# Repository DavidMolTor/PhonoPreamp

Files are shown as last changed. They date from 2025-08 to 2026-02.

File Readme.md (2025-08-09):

# Phono Preamplifier

A simple and precise phono preamplifier with a linear power supply.

## Introduction

This project contains the design for a phono preamplifier to be used with moving magnet capsules. It is optimized for low noise and distortion levels and has an accurate RIAA equalization stage.

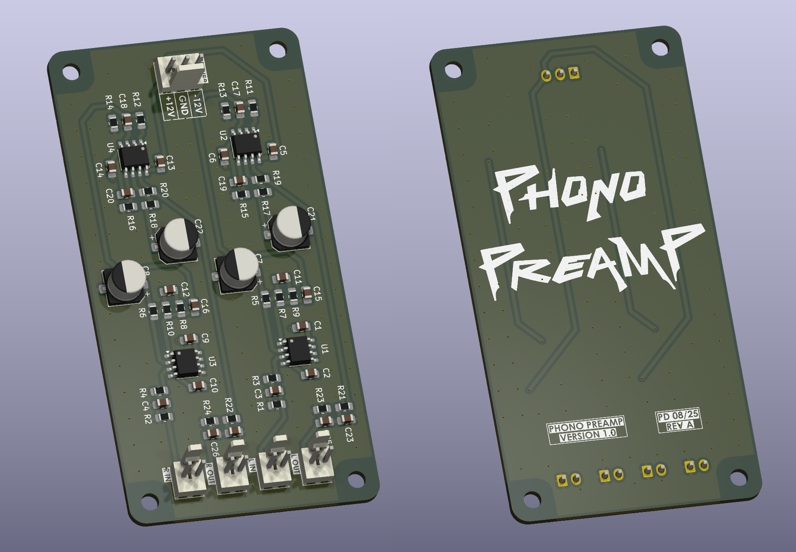
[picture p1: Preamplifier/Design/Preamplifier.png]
PREAMPLIFIER


The project also contains the design of a dual rail linear power supply in order to achive the lowest possible supply noise while keeping costs low.

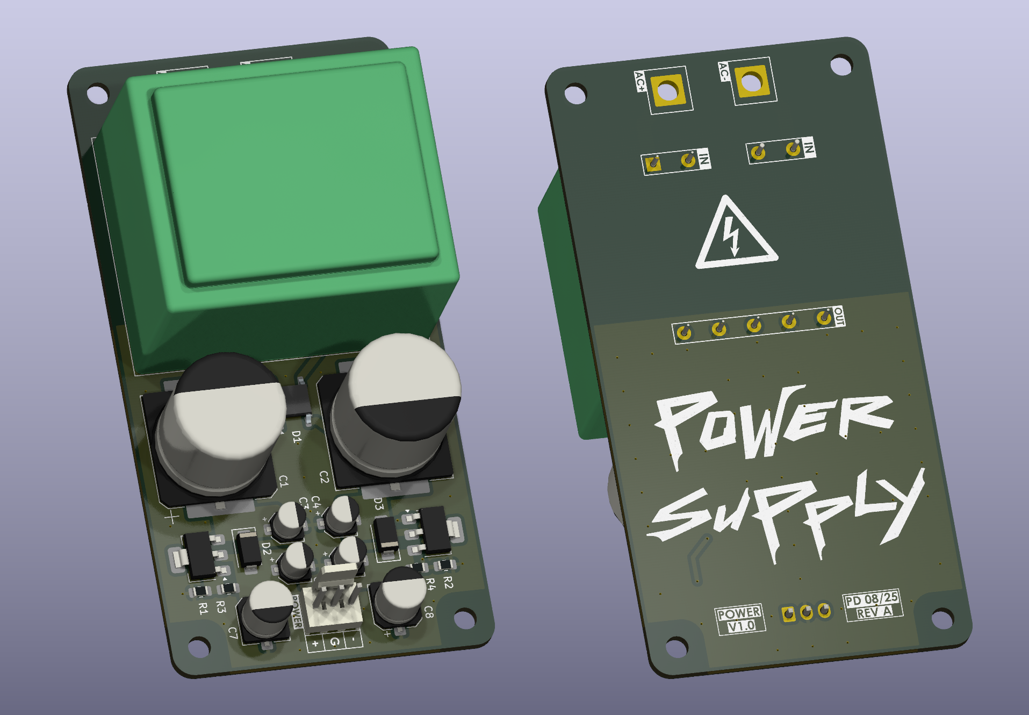
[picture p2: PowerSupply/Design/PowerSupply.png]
POWER SUPPLY


## Features

 - Compact form factor.

 - Precise RIAA equalization.

 - Low-noise linear power supply.

 - High-performance audio components.

 - Modular design for other applications.

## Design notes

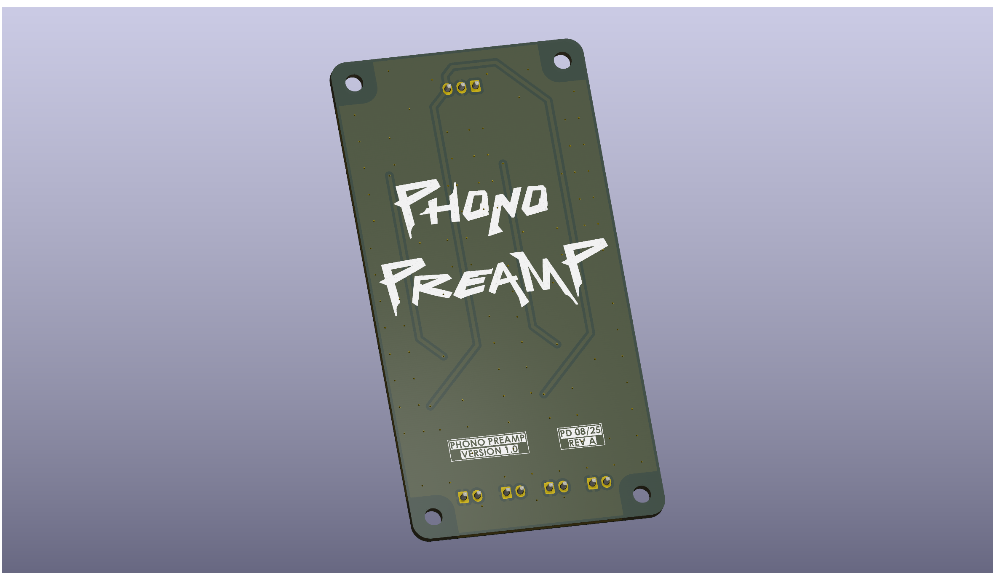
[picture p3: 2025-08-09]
Preamplifier/Design/Preamplifier_Back.png

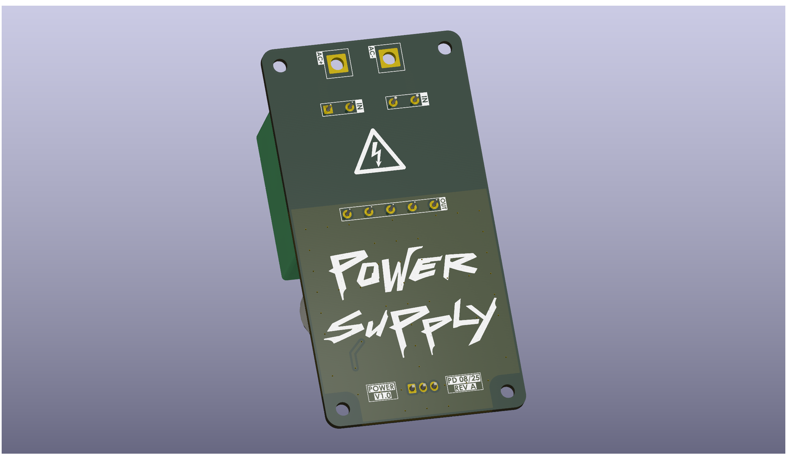
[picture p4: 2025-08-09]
PowerSupply/Design/PowerSupply_Back.png

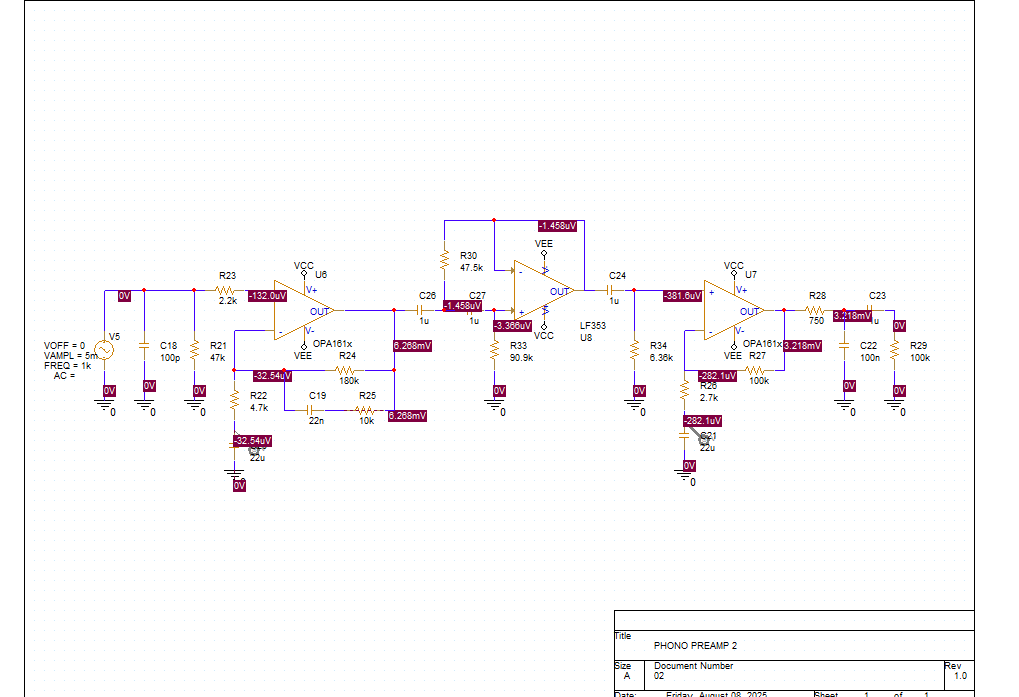
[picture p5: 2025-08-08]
Simulations/PHONOPREAMP.png

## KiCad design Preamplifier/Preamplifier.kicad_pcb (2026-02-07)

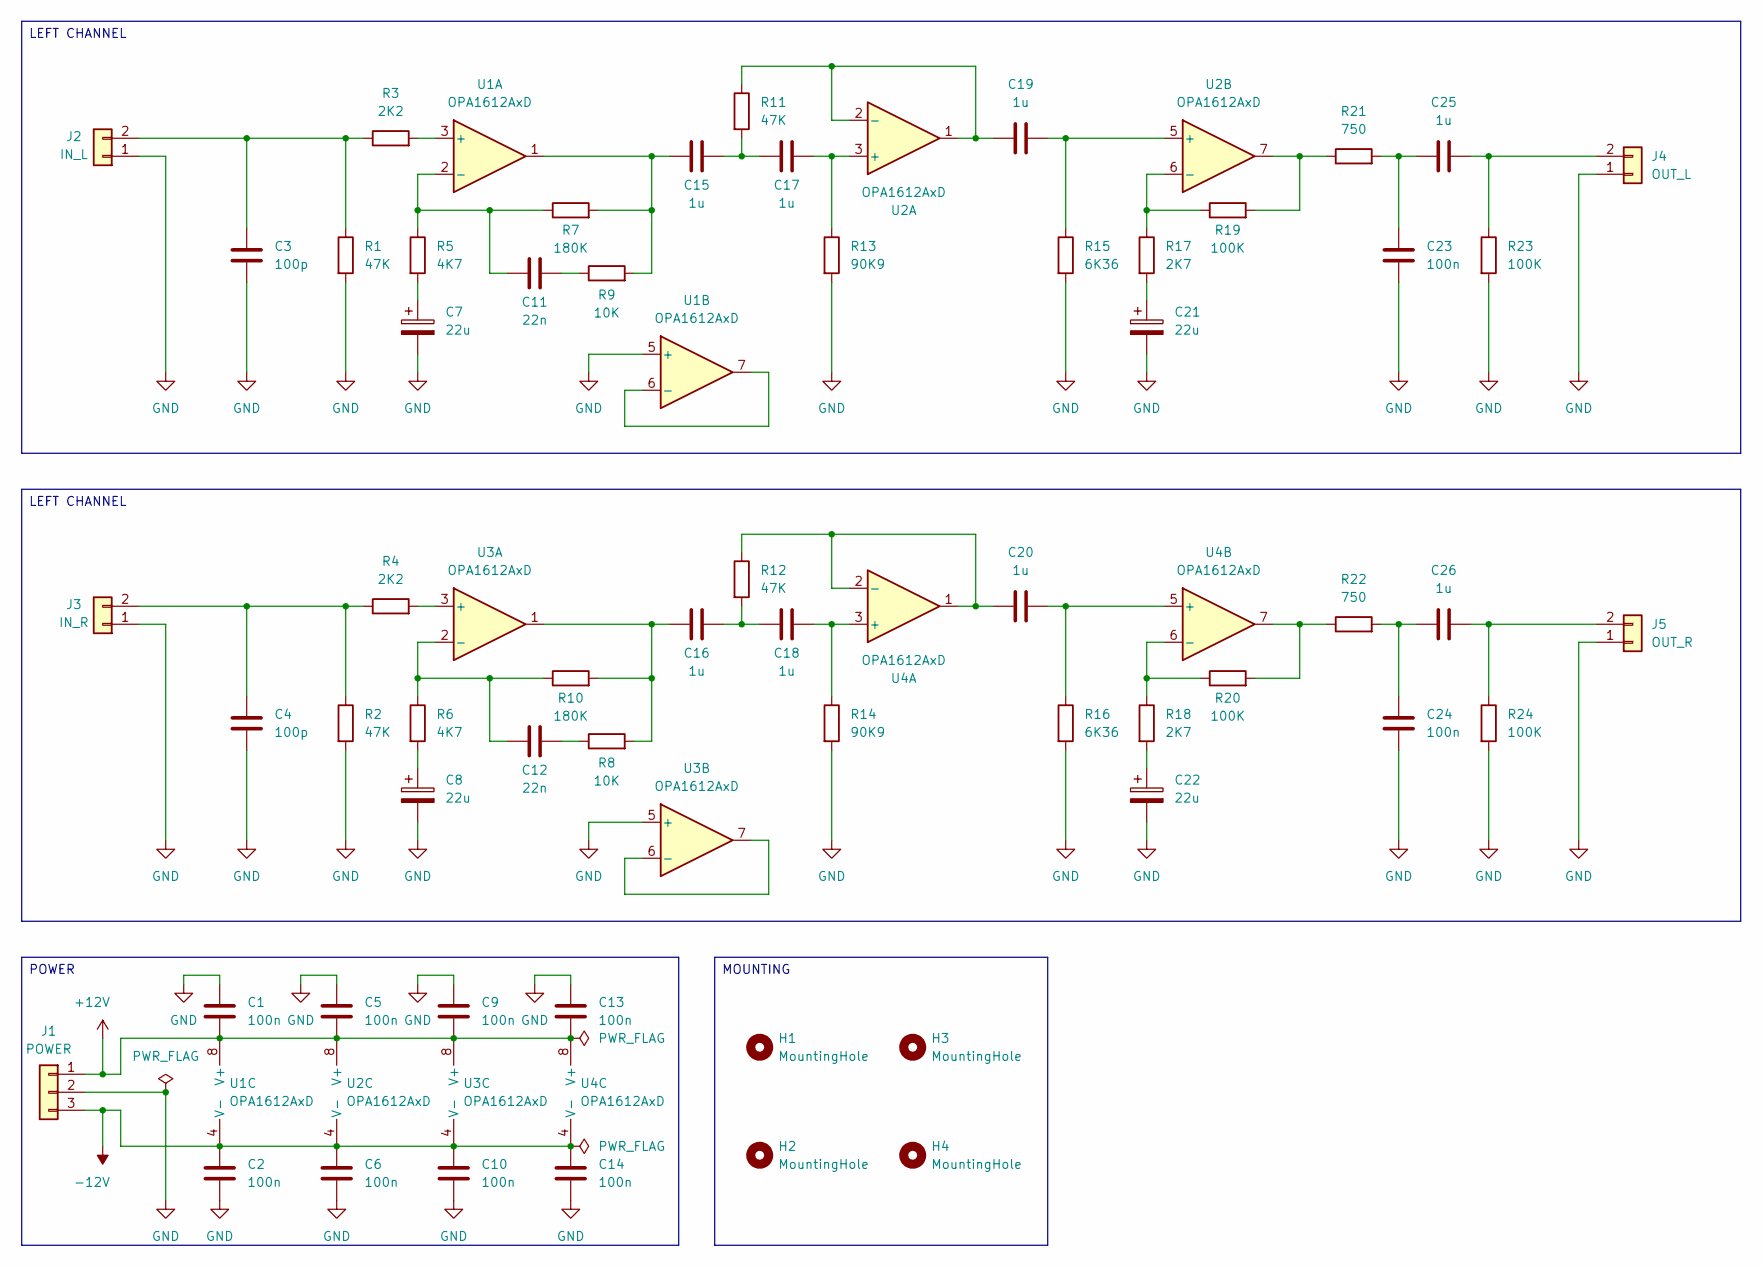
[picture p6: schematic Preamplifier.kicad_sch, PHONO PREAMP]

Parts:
C1, C2, C5, C6, C9, C10, C13, C14, C23, C24: 100n; C_0805_2012Metric_Pad1.18x1.45mm_HandSolder
C3, C4: 100p; C_0805_2012Metric_Pad1.18x1.45mm_HandSolder
C7, C8, C21, C22: 22u; CP_Elec_6.3x5.8
C11, C12: 22n; C_0805_2012Metric_Pad1.18x1.45mm_HandSolder
C15, C16, C17, C18, C19, C20, C25, C26: 1u; C_0805_2012Metric_Pad1.18x1.45mm_HandSolder
H1, H2, H3, H4: MountingHole; MountingHole_3.2mm_M3
J1: POWER; Molex_KK-254_1x03_P2.54mm_Vertical
J2: IN_L; Molex_KK-254_1x02_P2.54mm_Vertical
J3: IN_R; Molex_KK-254_1x02_P2.54mm_Vertical
J4: OUT_L; Molex_KK-254_1x02_P2.54mm_Vertical
J5: OUT_R; Molex_KK-254_1x02_P2.54mm_Vertical
R1, R2, R11, R12: 47K; R_0805_2012Metric_Pad1.20x1.40mm_HandSolder
R3, R4: 2K2; R_0805_2012Metric_Pad1.20x1.40mm_HandSolder
R5, R6: 4K7; R_0805_2012Metric_Pad1.20x1.40mm_HandSolder
R7, R10: 180K; R_0805_2012Metric_Pad1.20x1.40mm_HandSolder
R8, R9: 10K; R_0805_2012Metric_Pad1.20x1.40mm_HandSolder
R13, R14: 90K9; R_0805_2012Metric_Pad1.20x1.40mm_HandSolder
R15, R16: 6K36; R_0805_2012Metric_Pad1.20x1.40mm_HandSolder
R17, R18: 2K7; R_0805_2012Metric_Pad1.20x1.40mm_HandSolder
R19, R20, R23, R24: 100K; R_0805_2012Metric_Pad1.20x1.40mm_HandSolder
R21, R22: 750; R_0805_2012Metric_Pad1.20x1.40mm_HandSolder
U1, U2, U3, U4: OPA1612AxD; SOIC-8_3.9x4.9mm_P1.27mm

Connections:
+12V: C1.2, C5.2, C9.2, C13.2, J1.1, U1.8 (V+), U2.8 (V+), U3.8 (V+), U4.8 (V+)
-12V: C2.1, C6.1, C10.1, C14.1, J1.3, U1.4 (V-), U2.4 (V-), U3.4 (V-), U4.4 (V-)
GND: C1.1, C2.2, C3.2, C4.2, C5.1, C6.2, C7.2, C8.2, C9.1, C10.2, C13.1, C14.2, C21.2, C22.2, C23.2, C24.2, J1.2, J2.1, J3.1, J4.1, J5.1, R1.2, R2.2, R13.2, R14.2, R15.2, R16.2, R23.2, R24.2, U1.5 (+), U3.5 (+)
unnamed: C7.1, R5.2
unnamed: C8.1, R6.2
unnamed: C11.2, R9.1
unnamed: C12.2, R8.1
unnamed: C15.1, R7.2, R9.2, U1.1
unnamed: C15.2, C17.1, R11.2
unnamed: C16.1, R8.2, R10.2, U3.1
unnamed: C16.2, C18.1, R12.2
unnamed: C21.1, R17.2
unnamed: C22.1, R18.2
unnamed: C23.1, C25.1, R21.2
unnamed: C24.1, C26.2, R22.2
unnamed: C3.1, J2.2, R1.1, R3.1
unnamed: C4.1, J3.2, R2.1, R4.1
unnamed: C25.2, J4.2, R23.1
unnamed: C26.1, J5.2, R24.1
unnamed: R19.2, R21.1, U2.7
unnamed: R20.2, R22.1, U4.7
unnamed: R3.2, U1.3 (+)
unnamed: C11.1, R5.1, R7.1, U1.2 (-)
unnamed: U1.6 (-), U1.7
unnamed: C17.2, R13.1, U2.3 (+)
unnamed: C19.1, R11.1, U2.1, U2.2 (-)
unnamed: C19.2, R15.1, U2.5 (+)
unnamed: R17.1, R19.1, U2.6 (-)
unnamed: R4.2, U3.3 (+)
unnamed: C12.1, R6.1, R10.1, U3.2 (-)
unnamed: U3.6 (-), U3.7
unnamed: C18.2, R14.1, U4.3 (+)
unnamed: C20.1, R12.1, U4.1, U4.2 (-)
unnamed: C20.2, R16.1, U4.5 (+)
unnamed: R18.1, R20.1, U4.6 (-)

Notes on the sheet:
LEFT CHANNEL
MOUNTING
POWER

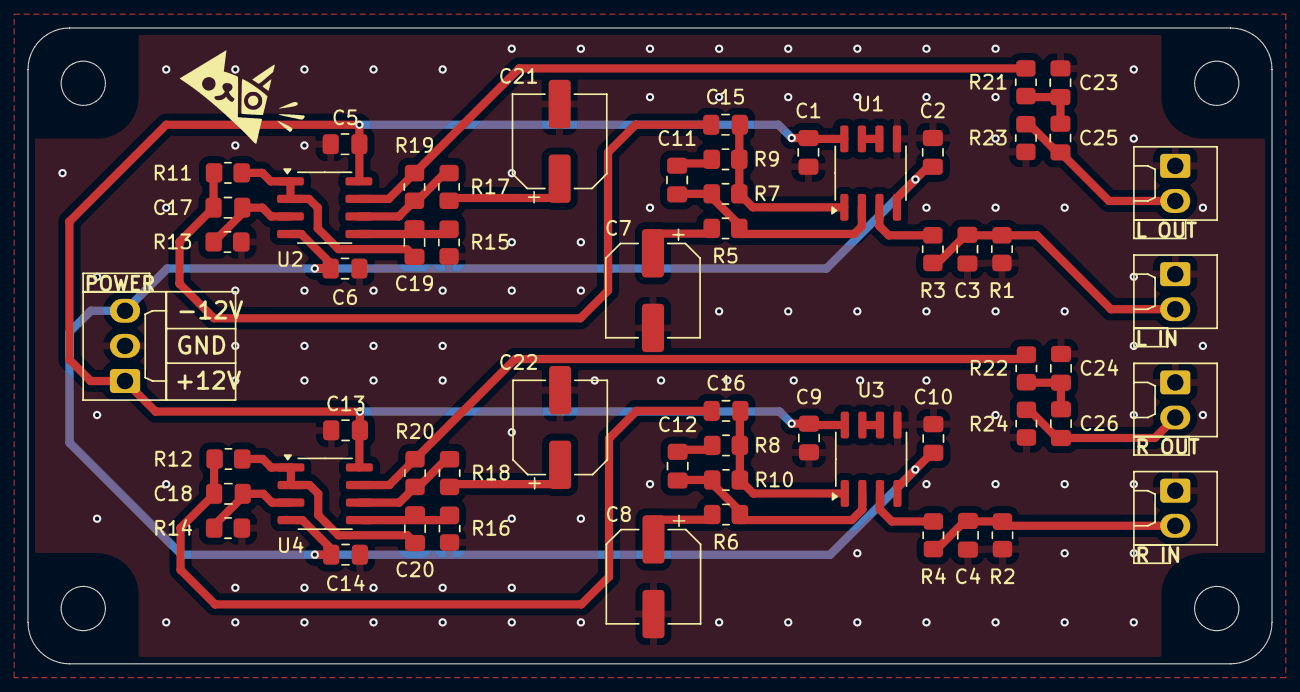
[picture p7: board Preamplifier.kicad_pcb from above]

Board: 2 copper layers, 90.0 x 46.0 mm, 63 parts (0 on the bottom side), 35 nets.

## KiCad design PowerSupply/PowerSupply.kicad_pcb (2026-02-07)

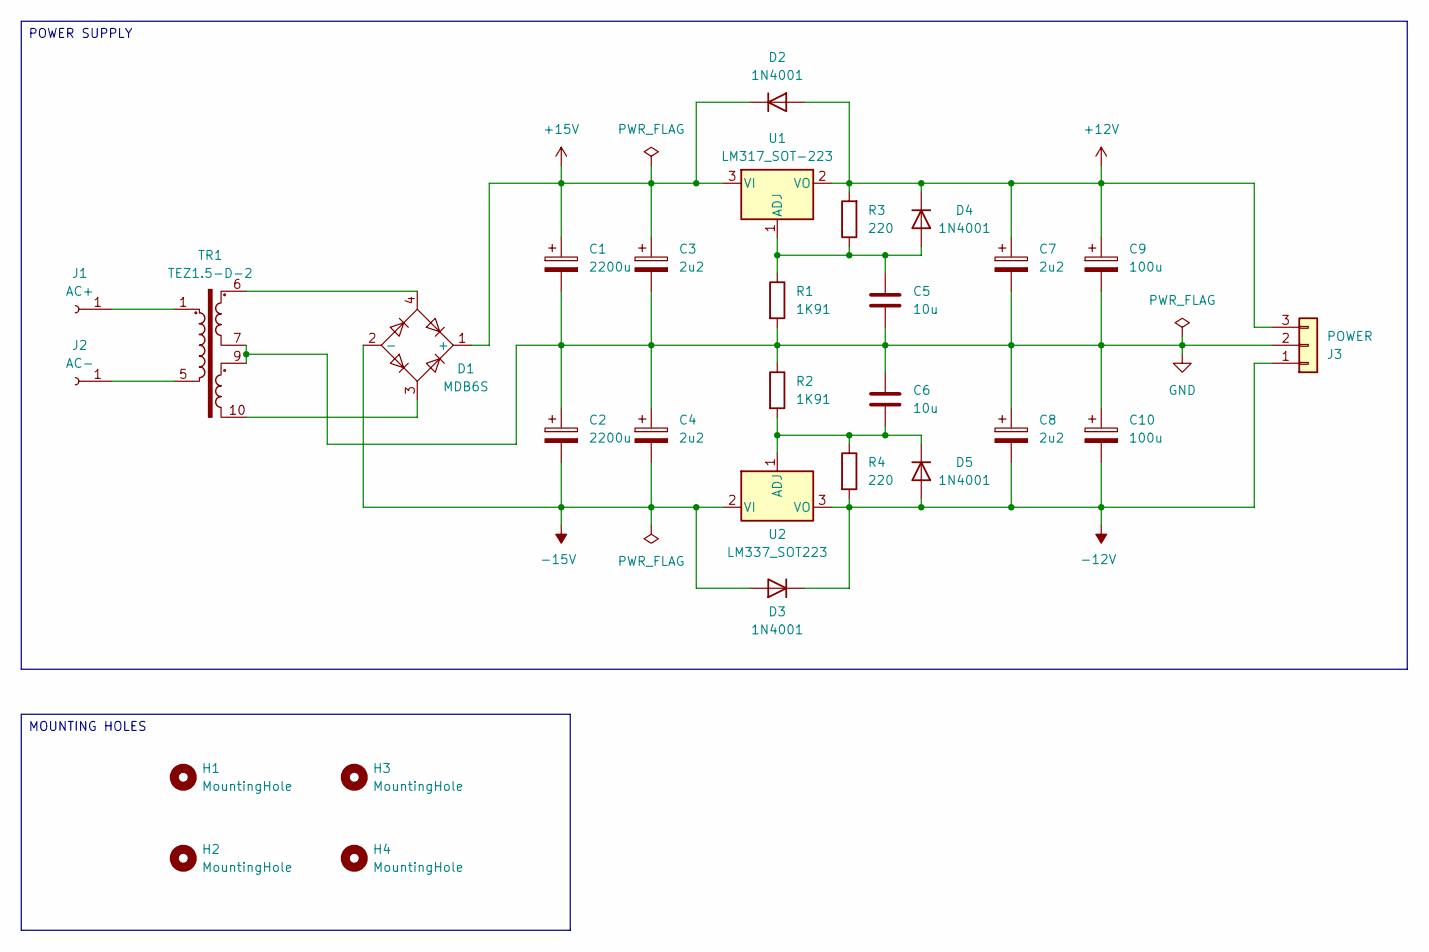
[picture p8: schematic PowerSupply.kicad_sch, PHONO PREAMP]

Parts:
C1, C2: 2200u; CP_Elec_16x17.5
C3, C4, C7, C8: 2u2; CP_Elec_4x5.4
C5, C6: 10u; C_0805_2012Metric_Pad1.18x1.45mm_HandSolder
C9, C10: 100u; CP_Elec_6.3x7.7
D1: MDB6S; TSSOP-4_4.4x5mm_P4mm
D2, D3: 1N4001; D_SMA
D4, D5: 1N4001; D_SOD-323
H1, H2, H3, H4: MountingHole; MountingHole_3.2mm_M3
J1: AC+; SolderWire-2.5sqmm_1x01_D2.4mm_OD4.4mm
J2: AC-; SolderWire-2.5sqmm_1x01_D2.4mm_OD4.4mm
J3: POWER; Molex_KK-254_1x03_P2.54mm_Vertical
R1, R2: 1K91; R_0805_2012Metric_Pad1.20x1.40mm_HandSolder
R3, R4: 220; R_0805_2012Metric_Pad1.20x1.40mm_HandSolder
TR1: TEZ1.5-D-2; TRANSFORMER_TEZ-35X42
U1: LM317_SOT-223; SOT-223-3_TabPin2
U2: LM337_SOT223; SOT-223-3_TabPin2

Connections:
+12V: C7.1, C9.1, D2.2 (A), D4.1 (K), J3.3, R3.2, U1.2 (VO)
+15V: C1.1, C3.1, D1.1 (+), D2.1 (K), U1.3 (VI)
-12V: C8.2, C10.2, D3.1 (K), D5.2 (A), J3.1, R4.2, U2.3 (VO)
-15V: C2.2, C4.2, D1.2 (-), D3.2 (A), U2.2 (VI)
GND: C1.2, C2.1, C3.2, C4.1, C5.2, C6.1, C7.2, C8.1, C9.2, C10.1, J3.2, R1.2, R2.1, TR1.7, TR1.9
unnamed: D1.3, TR1.10
unnamed: D1.4, TR1.6
unnamed: C5.1, D4.2 (A), R1.1, R3.1, U1.1 (ADJ)
unnamed: C6.2, D5.1 (K), R2.2, R4.1, U2.1 (ADJ)
unnamed: J1.1, TR1.1
unnamed: J2.1, TR1.5

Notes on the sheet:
POWER SUPPLY
MOUNTING HOLES

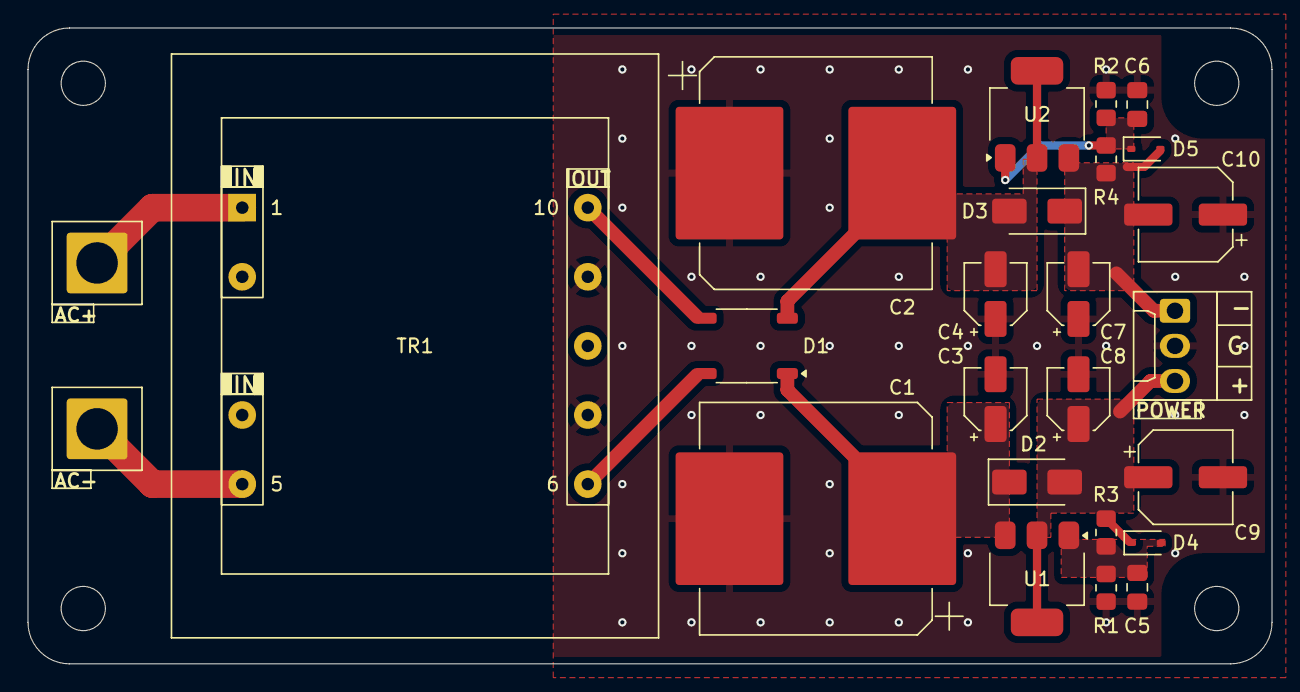
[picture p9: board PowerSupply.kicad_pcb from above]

Board: 2 copper layers, 90.0 x 46.0 mm, 29 parts (0 on the bottom side), 11 nets.

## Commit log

2024-05-23 Updated ignore filters
    [PHONOPREAMP1.DSN, PHONOPREAMP2.DSN, PHONOPREAMP3.DSN]
2025-08-05 Simulation and PCB Project
    Updated the simulation project.
    Added a PCB design project.
    Deleted unused simulations.
    [PHONOPREAMP.DSN, PHONOPREAMP1.DSN, PHONOPREAMP2.DSN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]
2025-08-06 Main project
    Added new schematic sheets.
    Updated main project.
    [PhonoPreamp.kicad_sch, Power.kicad_sch, Preamp.kicad_sch]
2025-08-07 Power schematic
    Updated the power schematic sheet.
    [Power.kicad_sch]
2025-08-08 Project structure
    Updated the project structure.
    Updated the power supply schematic.
    [PhonoPreamp.kicad_sch, Power.kicad_sch, PowerSupply.kicad_pcb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]
2025-08-08 Power Supply Board
    Updated the power supply board.
    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
    [PowerSupply.kicad_pcb, PowerSupply.kicad_sch]
2025-08-08 Preamplifier Simulation
    Updated the preamplifier simulation project.
    Added a simpler preamplifier for testing.
    [PHONOPREAMP.DSN]
2025-08-08 Preamplifier Simulation
    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
    [PHONOPREAMP.DSN]
2025-08-08 Preamplifier Schematic
    Added the preamplifier schematic.
    Updated the preamplifier project.
    [PowerSupply.kicad_sch, Preamplifier.kicad_sch]
2025-08-08 Preamplifier Board
    Added a preamplifier channel to the board.
    [Preamplifier.kicad_pcb, Preamplifier.kicad_sch]
2025-08-08 Gerber Ignore
    Updated the gitignore file.
2025-08-09 Preamplifier Board
    Updated the preamplifier board design.
    [Preamplifier.kicad_pcb, Preamplifier.kicad_sch]
2025-08-09 Power Supply Board
    Updated the power supply board design.
    [PowerSupply.kicad_pcb, PowerSupply.kicad_sch]
2025-08-09 Board Designs
    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
    [PowerSupply.kicad_pcb, PowerSupply.kicad_sch, Preamplifier.kicad_pcb]
2025-08-09 Picture Models
    Added a set of pictures for the power supply board.
    Added a set of pictures for the preamplifier board.
2025-08-11 Power Supply Design
    Set the power supply project version to 1.1.
    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
    [PowerSupply.kicad_pcb, PowerSupply.kicad_sch]
2025-08-12 Power Supply Design
    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
    [PowerSupply.kicad_pcb]
2025-08-12 Board 3D Models
    Added a 3D model for the power supply board.
    Added a 3D model for the preamplifier board.
2025-10-29 Preamplifier Board
    Updated the preamplifier schematic.
    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
    [Preamplifier.kicad_pcb, Preamplifier.kicad_sch]
2026-02-07 Company name
    Updated the company name for all project files.
    [PowerSupply.kicad_pcb, PowerSupply.kicad_sch, Preamplifier.kicad_pcb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]
